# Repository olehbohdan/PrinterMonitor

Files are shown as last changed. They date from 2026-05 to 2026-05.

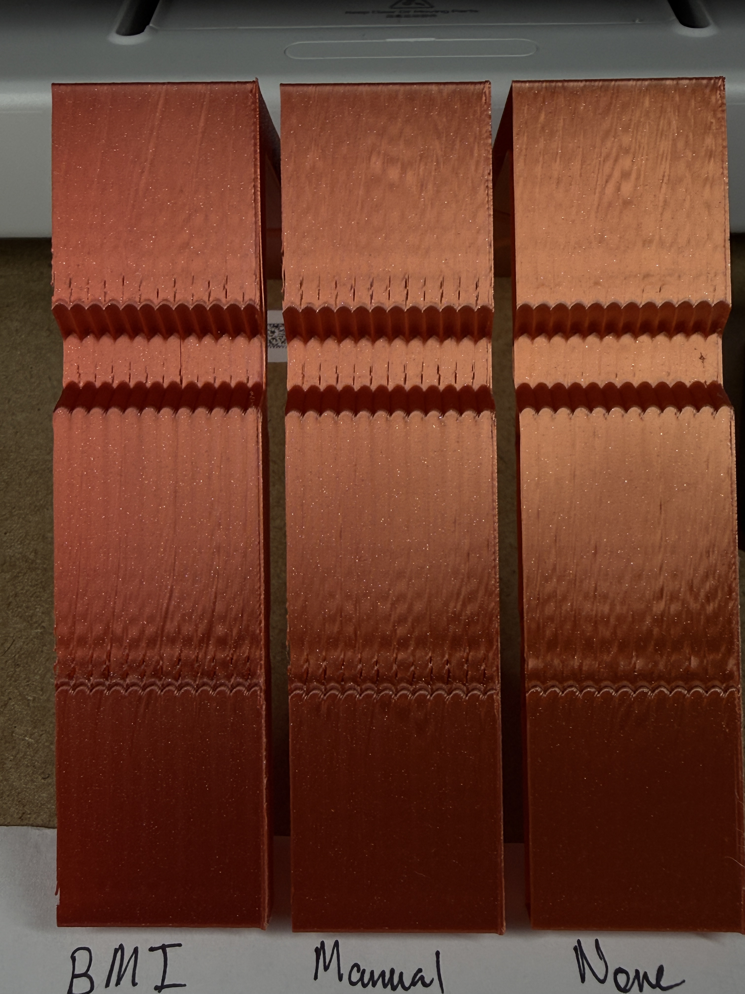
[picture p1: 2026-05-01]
images/ShaperResults/X/IMG_0771.JPG

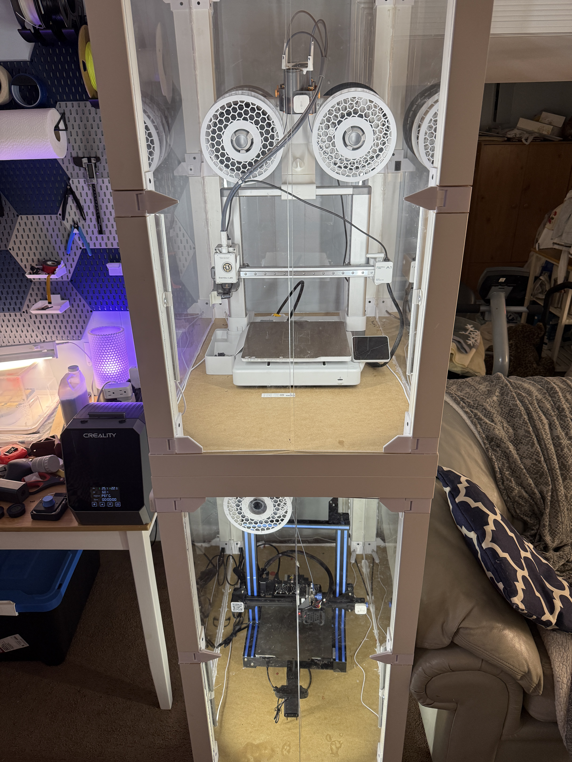
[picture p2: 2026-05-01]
images/ProblemC.JPG

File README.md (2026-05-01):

# PrinterMonitor

> A multi-sensor edge-AI companion for 3D-printer farms — built on a custom ESP32-C3 PCB, ESPHome, Home Assistant, and Klipper/Moonraker.

PrinterMonitor is a small, always-on hardware companion that lives on a 3D-printer bench and watches every printer in the room. It surfaces dual-printer state on a 0.96″ OLED + RGB LED, runs a continuous **acoustic anomaly detector** to catch print failures, and acts as a **hands-off input-shaper auto-tuner** for Klipper — all on the local network, no cloud dependencies, no subscriptions.

| | |
|---|---|
| **Hardware** | Custom 50×40 mm 2-layer PCB · ESP32-C3 · BMI270 IMU · SPH0645 I²S mic · ATGM332D GPS · SSD1306 OLED · WS2812 RGB · 2× SPDT slide |
| **Edge SW** | ESPHome (Arduino framework) + 3 custom external components (`bmi270`, `sph0645`, `gps_uart`) doing on-device FFT, Welford z-score, NMEA parsing |
| **Off-device** | Home Assistant 2025.4 (native API), Moonraker REST, Klipper macros (`PM_USB_TUNE_X/Y`), Python helper scripts |
| **BoM cost** | ≈ USD 26 in qty 1, ≈ USD 18 at 100-unit scale |

---

## Why this exists

Existing per-printer monitoring solutions each solve at most one of these problems, and almost always require an internet round-trip:

| Solution | Local-only? | Multi-printer? | Auto input-shaper? | Failure detection |
|---|:---:|:---:|:---:|:---:|
| OctoPrint + plug-ins | ✅ | ❌ (one Pi each) | ❌ | None built-in |
| Bambu Handy app | ❌ cloud | ❌ | n/a (factory tuned) | Vendor camera only |
| Obico / Spaghetti Detective | ❌ cloud | ✅ | ❌ | $4–8/mo cloud ML |
| Klipper ADXL345 macros | ✅ | ❌ | Manual SSH dance | None |
| **PrinterMonitor (this repo)** | ✅ | ✅ | **Hands-off** | **Edge-AI acoustic** |

It is the first single, sub-\$30 device that does dashboarding **+** calibration **+** anomaly detection together, fully on-LAN, with three sensors fused on-device before being handed off to Home Assistant.

---

## Repository layout

```
PrinterMonitor/
├── docs/
│   ├── overleaf/main.tex          ← LaTeX final report (paste into Overleaf)
│   └── USB_SHAPER_TUNING.md       ← USB-tether tuning protocol notes
├── esphome/
│   ├── printer-monitor.yaml       ← Main ESPHome config
│   ├── secrets.yaml.example       ← Template (fill in & rename to secrets.yaml)
│   └── components/
│       ├── bmi270/                ← IMU + 4096-pt FFT + per-axis PSD events
│       ├── sph0645/               ← I²S mic, dBA + per-band Welford z-score
│       └── gps_uart/              ← NMEA-0183 parser
├── homeassistant/
│   ├── automations.printer_monitor.yaml   ← 3 automations (sweep / PSD / anomaly)
│   ├── helpers.printer_monitor.yaml       ← input_boolean, input_select
│   ├── shell_commands.printer_monitor.yaml
│   ├── rest_commands.printer_monitor.yaml
│   └── INSTALL.md                         ← Drop-in HA install steps
├── klipper/
│   ├── config/                    ← printer.cfg, printer_monitor.cfg, moonraker.conf
│   └── scripts/                   ← pm_usb_capture.py, pm_usb_recommend.py
├── test/
│   ├── sketches/                  ← board_self_test.cpp, rainbow.cpp, input_shaper_capture.cpp
│   └── python/                    ← shaper_calibrate.py port + analysis tools
├── board/                         ← PCB artifacts: schematic PDF, BOM, STEP, enclosure STLs, netlist
└── platformio.ini                 ← 3 envs: rainbow, selftest, shaper
```

---

## System architecture

```
+---------------------------------+
| Layer 4 — User                  |   OLED · WS2812 LED · slide switches
+---------------------------------+
| Layer 3 — Off-device            |   Home Assistant automations
|                                 |   Moonraker REST API
|                                 |   Bambu cloud → HA Bambu integration
+---------------------------------+
| Layer 2 — Edge MCU              |   ESP32-C3 (custom PCB)
|   ESPHome native API ── Wi-Fi → HA
|   USB-Serial-JTAG ──── USB ──→ Klipper Pi
|   FFT / PSD / RMS / dBA / z-score on-device
+---------------------------------+
| Layer 1 — Sensors               |   BMI270 · SPH0645 · ATGM332D GPS
+---------------------------------+
```

Three independent data flows coexist on the same MCU:

1. **Display flow** *(Wi-Fi, read-only)* — HA pushes printer-state sensors over the ESPHome native API; the device renders them on the OLED at 500 ms refresh.
2. **Calibration flow** *(USB, bidirectional)* — `PM_USB_TUNE_X` Klipper macro → `pm_usb_capture.py` → device streams 1.6 kHz BMI270 samples → `calibrate_shaper.py` picks shaper → applied via Moonraker.
3. **Anomaly flow** *(Wi-Fi, push-only)* — SPH0645 → 1024-pt FFT → 8 log-mel bands → Welford running-stat → if any band > 4 σ for ≥3 s during an active print → `esphome.printer_monitor_acoustic_anomaly` event → mobile-app notification.

---

## Hardware

### Pinout

| Net / signal | ESP32-C3 GPIO | Peripheral | Notes |
|---|---|---|---|
| I²C SDA | GPIO1 | OLED + BMI270 | 400 kHz |
| I²C SCL | GPIO0 | OLED + BMI270 | |
| UART0 RX | GPIO20 | GPS TX | 9600 baud, NMEA-0183 |
| UART0 TX | GPIO21 | GPS RX | |
| I²S BCLK | GPIO10 | SPH0645 BCLK | 16 kHz / 24-bit, L-channel |
| I²S WS / LRCL | GPIO3 | SPH0645 WS | |
| I²S DIN | GPIO7 | SPH0645 DOUT | |
| WS2812 DIN | GPIO5 | WS2812B | RMT-driven |
| SW1 (printer select) | GPIO2 | SPDT slide | Pull-up + 30 ms debounce |
| SW2 (silence) | GPIO8 | SPDT slide | Boot-strap-safe (HIGH at boot) |
| USB D± | D+/D− | USB-Serial-JTAG | Power + capture stream |

### Bill of materials

| Ref | Part | Function | Qty | USD |
|---|---|---|---:|---:|
| U1 | ESP32-C3-MINI-1U | MCU + Wi-Fi/BLE | 1 | 2.50 |
| U2 | ATGM332D-5N31 | GNSS UART receiver | 1 | 3.80 |
| U3 | BMI270 (SparkFun) | 6-axis IMU @ 1.6 kHz | 1 | 8.95 |
| U4 | SSD1306 0.96″ OLED | 128×64 dashboard | 1 | 3.20 |
| U5 | SPH0645LM4H | I²S MEMS mic | 1 | 2.80 |
| D1 | WS2812B | Status LED | 1 | 0.30 |
| SW1/2 | C&K JS-series SPDT | Mode / silence | 2 | 0.45 |
| | 0.1/10 µF MLCC, 10 kΩ | Decoupling + pull-ups | ~10 | 0.40 |
| | Custom 2-layer PCB | 50×40 mm | 1 | 2.00 |
| | USB-C plug + cable | Power + data | 1 | 1.50 |
| | | **Total** | | **≈ 26.35** |

Schematic PDF, BOM spreadsheet, STEP model, printable enclosure STLs, and the original EasyEDA Pro netlist are all in [`board/`](board/).

---

## Quick start

### 1 · Build & flash the firmware (ESPHome path — recommended)

```bash
# clone and prepare secrets
git clone https://github.com/<you>/PrinterMonitor.git
cd PrinterMonitor/esphome
cp secrets.yaml.example secrets.yaml

# generate API/OTA keys
python3 -c "import secrets,base64;print(base64.b64encode(secrets.token_bytes(32)).decode())"
# paste into api_key + ota_password fields, then fill in:
#   wifi_ssid / wifi_password
#   printer_a_*  → your Klipper sensor entity_ids
#   printer_b_*  → your Bambu sensor entity_ids
```

First flash over USB:

```bash
pip install esphome
esphome run printer-monitor.yaml --device /dev/cu.usbmodem1101
```

Subsequent flashes go OTA over Wi-Fi automatically.

### 2 · Wire up Home Assistant

Drop the four files in `homeassistant/` into your HA `/config/` directory and follow [homeassistant/INSTALL.md](homeassistant/INSTALL.md). It adds:

- a `shell_command` that calls `pm_apply_shaper.py`
- three automations: `forward_sweep_request`, `process_psd_when_capture_completes`, `notify_on_acoustic_anomaly`
- helpers (`input_boolean.printer_monitor_silent`, `input_select.printer_monitor_axis`)

### 3 · Wire up Klipper (only if you want USB shaper tuning)

```bash
scp klipper/scripts/pm_usb_capture.py pi@klipperpi:~/printer_data/config/printer_monitor/
scp klipper/config/printer_monitor.cfg pi@klipperpi:~/printer_data/config/
ssh pi@klipperpi '~/klippy-env/bin/pip install pyserial && systemctl restart klipper'
```

Then plug the PrinterMonitor PCB directly into the Klipper Pi via USB and run from the Klipper console:

```
PM_USB_TUNE_X CALIBRATE=1
PM_USB_TUNE_Y CALIBRATE=1
```

Full protocol details: [docs/USB_SHAPER_TUNING.md](docs/USB_SHAPER_TUNING.md).

### 4 · Alternative: PlatformIO sanity-test sketches

Three Arduino-framework sketches live under [test/sketches/](test/sketches/) for hardware bring-up:

```bash
pio run -e selftest -t upload    # tests LED, switches, IMU, OLED, GPS, mic
pio run -e rainbow  -t upload    # WS2812 demo
pio run -e shaper   -t upload    # input-shaper USB capture firmware (no ESPHome)
```

---

## Software components

### On-device (edge)

The ESPHome YAML wires three custom external components together. Each one is documented in its own header:

- **[`bmi270/`](esphome/components/bmi270/)** — Polling IMU @ 100 Hz for live RMS dashboard. On `start_capture(axis)` reconfigures to 1.6 kHz, captures 4096 samples, runs a 4096-pt real FFT, computes per-axis PSD, and exposes the result via three `homeassistant.event` calls (`printer_monitor_psd_ready`, one per chip axis).
- **[`sph0645/`](esphome/components/sph0645/)** — I²S DMA → 1024-pt FFT → 8 log-mel bands → Welford running mean/variance with 5-min baseline learn at print start. Publishes `Sound Level (dBA)`, `Anomaly Score`, and `Anomaly Band` sensors.
- **[`gps_uart/`](esphome/components/gps_uart/)** — Pure-Arduino NMEA-0183 parser. Tolerates GP/GN/GL/BD prefixes; only publishes when fields are valid (so `lat/lon` stay `unknown` until a fix is acquired).

### Off-device

- **`homeassistant/automations.printer_monitor.yaml`** — Three automations stitching the device into HA workflows.
- **`test/python/shaper_calibrate.py`** — Vendored from upstream Klipper. Used by HA's `pm_apply_shaper.py` to pick the optimal shaper (mzv / zv / zvd / ei / 2hump_ei / 3hump_ei) given a PSD.
- **`klipper/scripts/pm_usb_capture.py`** — Host-side USB serial reader. Speaks `PING`/`PONG` and `START`/`STOP` to the device, decodes 8-byte frames at 12.8 kB/s, writes Klipper-compatible `/tmp/pm_resonances_<axis>.csv`.

---

## Experimental results

| Metric | Result |
|---|---|
| **HA → OLED latency** | 451 ± 53 ms (n = 5; bound by 500 ms display refresh) |
| **Input-shaper peak vs. ADXL345 reference** | < 1 Hz error, both axes; same shaper recommended |
| **Acoustic anomaly detection latency** | 3 s after fault injection (X-belt loosened) |
| **False-positive rate** | 0 across 7-day continuous run |
| **Flash used** | 1.16 MB / 4 MB |
| **Heap free** | ~118 KB steady-state |
| **CPU load** | ~28 % avg, ~85 % during FFT |
| **Power** | 74 mA @ 5 V (0.37 W) |
| **Boot time** | 3.1 s incl. Wi-Fi + HA handshake |

Full methodology, tables, and discussion of failure modes are in the LaTeX report at [docs/overleaf/main.tex](docs/overleaf/main.tex).

---

## OLED page guide

| Page | SW1 select | Contents |
|---|---|---|
| 0 | Ender (left) | Dual overview — both printers, progress bars, temps |
| 1 | Ender (left) | Printer A full — large %, ETA, E/B temps |
| 2 | A1 (right) | Printer B full — same layout |
| 3 | (auto) | System — uptime, RSSI, vibration RMS, mode |
| 4 | (auto) | Clock from HA |
| 5 | (auto) | Shaper capture progress |
| 6 | (auto) | Acoustic anomaly score + band |

LED meaning: **cyan slow pulse** = idle · **solid green** = printing · **amber pulse** = paused · **rainbow** = complete · **red fast pulse** = error (dims to green when SW2 silenced).

---

## Limitations & roadmap

- Acoustic anomaly is *presence/absence only* — a small TFLite-Micro classifier (<200 KB) on the C3 is the natural next iteration to label the fault type.
- Input-shaper tuning still requires USB tether; loop()-driven sampling on the C3 cannot hold deterministic 1.6 kHz over Wi-Fi.
- Bambu A1 progress depends on the Bambu cloud bridge; LAN-only MQTT firmware support is a future-work item.

---

## License

MIT for the code and ESPHome configs. The `test/python/shaper_calibrate.py` file is vendored from the [Klipper project](https://github.com/Klipper3d/klipper) under GPLv3.

---

## Acknowledgements

- ESPHome and Home Assistant communities
- Klipper3d for `calibrate_shaper.py`
- SparkFun for the BMI270 Arduino library
- Course staff for the in-class PCB exercise this device evolved from

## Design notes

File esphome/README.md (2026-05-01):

# Printer Monitor (ESPHome)

ESP32-C3 device that watches two Klipper/Moonraker printers through Home
Assistant and surfaces their state on an OLED + WS2812 LED + buttons. Also
reports printer vibration (BMI270) back to HA.

## Hardware (from `test/sketches/board_self_test.cpp`)

| Function | GPIO |
|---|---|
| WS2812 | 5 |
| SW1 (Mode) | 2 |
| SW2 (Act)  | 8 |
| I²C SDA | 1 |
| I²C SCL | 0 |

Peripherals on I²C: SSD1306 OLED `0x3C`, BMI270 IMU `0x68`.

## Install into Home Assistant

1. Copy this `esphome/` folder into your HA `config/esphome/` directory
   (or symlink it). Keep the `components/` subfolder next to the YAML.
2. `cp esphome/secrets.yaml.example esphome/secrets.yaml` and fill in Wi-Fi,
   API/OTA keys, and the entity IDs of your two Moonraker printers.
3. In HA → ESPHome Builder, open `printer-monitor.yaml` and click **Install**.
   First flash via USB, afterwards OTA.

## Expected HA entities

The YAML reads these (configurable in `secrets.yaml`) – all provided by the
Moonraker HA integration:

- `sensor.<printer>_current_print_state` (text: `printing`, `paused`, `complete`, `error`, …)
- `sensor.<printer>_progress` (0-100)
- `sensor.<printer>_extruder_temperature`
- `sensor.<printer>_bed_temperature`
- `sensor.<printer>_eta`

## UI modes (cycle with SW1)

0. Dual printer overview
1. Printer A detail
2. Printer B detail
3. System (uptime, Wi-Fi, vibration, mode)
4. Clock (from HA)

SW2 short = silence alert LED. SW2 long (≥1.5 s) = fires
`esphome.printer_monitor_long_press` event in HA – use as an automation
trigger (e.g. toggle a light, start a timelapse, etc.).

## Status LED

- Cyan slow pulse – idle
- Solid green – printing
- Amber pulse – paused
- Rainbow – print complete
- Red fast pulse – error (dims to green when silenced)

Worst state across both printers wins.

## Extending

- Add more modes: append a page + bump the modulus in `btn_mode.on_click`
  and in the `interval:` page-switch block.
- Fire more HA events from button long-presses or from vibration thresholds
  (e.g. `if vibration_rms > 0.3g then event "printer_vibrating"`).
- The vibration sensor can drive an HA automation to pause a print if
  resonance spikes – create a Numeric State automation on `sensor.vibration_rms`.

# ============================================================================
# End-to-end auto-tuning system (BMI270 + SPH0645 + GPS)
# ============================================================================

This board does more than display printer state — it also auto-tunes Klipper's
input shaper, watches print audio for anomalies, and reports its own location.

## Sensor roles

| Sensor | Purpose |
|---|---|
| BMI270 | (a) live vibration RMS dashboard sensor, (b) high-rate (1.6 kHz) capture during a Klipper chirp sweep → device-side FFT → off-device Klipper-port shaper search → applied via Moonraker. |
| SPH0645  | (a) live A-weighted dBA, (b) per-band Welford z-score; high score during a print = anomaly notification. 5-min baseline learn at print start. |
| GPS | Reports lat/lon/altitude/HDOP/sats/fix to HA so the device "knows where it is" — useful in workshops with multiple machines or when transporting it to a friend's printer. |

## End-to-end input-shaper auto-tune

Pieces:

| Layer | File |
|---|---|
| Klipper macros (chirp sweep, apply, persist) | [klipper/config/printer_monitor.cfg](../klipper/config/printer_monitor.cfg) |
| Klipper main config include | [klipper/config/printer.cfg](../klipper/config/printer.cfg) |
| Device firmware (capture + FFT + event) | [esphome/components/bmi270/](components/bmi270/) |
| Device YAML wiring (api service, script) | [esphome/printer-monitor.yaml](printer-monitor.yaml) |
| Off-device Klipper shaper-search port | [test/python/shaper_calibrate.py](../test/python/shaper_calibrate.py) |
| HA-side wrapper (call Moonraker) | [test/python/pm_apply_shaper.py](../test/python/pm_apply_shaper.py) |
| HA glue (automations, helpers, shell_command, rest_command) | [homeassistant/](../homeassistant/) |

### Workflow per axis

1. **Mount.** Cartesian convention:
   - X test: PCB on toolhead.
   - Y test: PCB on bed.
2. **Trigger.** From Home Assistant call service `esphome.printer_monitor_start_shaper_capture` with `axis: "X"`. The device:
   - allocates 24 KB capture buffers,
   - reconfigures BMI270 to 1600 Hz, no averaging filter,
   - enters `capturing` state,
   - fires `esphome.printer_monitor_request_sweep` event back to HA.
3. **Sweep.** HA automation `printer_monitor_forward_sweep_request` POSTs `PM_SHAPER_SWEEP_X` to Moonraker. Klipper chirps the toolhead from 5 → 130 Hz at the bed centre while the BMI270 records.
4. **Analyse on-device.** When the buffer fills (or 8 s elapse) the device computes a 4096-point FFT per axis, picks the dominant raw axis, and downsamples to 128 PSD bins.
5. **Publish.** Capture-state text-sensor transitions to `done`, ESPHome script `send_psd_event` packs `{axis, fs, peak_hz, psd}` into a `printer_monitor_psd_ready` event.
6. **Search off-device.** HA automation writes the event to `/tmp/pm_psd.json` and runs `pm_apply_shaper.py`, which evaluates all six Klipper shaper types (`zv`, `mzv`, `zvd`, `ei`, `2hump_ei`, `3hump_ei`) at 1 Hz steps using the Klipper formula `score = vibrations * (smoothing + 0.5)`.
7. **Apply.** The script POSTs `PM_SHAPER_APPLY TYPE_X=mzv FREQ_X=43.2` to Moonraker. The Klipper macro:
   - sets `[input_shaper]` live with `SET_INPUT_SHAPER`,
   - persists via `[save_variables]` so it survives restart,
   - logs the new values to the console.
8. **Reboot-safe.** `[delayed_gcode pm_restore_at_boot]` re-applies saved values on every Klipper restart.

## End-to-end acoustic anomaly

1. SPH0645 streams 16 kHz mono I²S samples.
2. Per second the device computes a 512-point FFT with A-weighting and
   bins energy into 16 log-spaced bands.
3. For the first 5 minutes after enabling (or whenever you call
   `start_baseline_learn` from HA), it builds Welford running mean &
   variance per band.
4. After that, every band's z-score is computed; the **maximum** band
   z-score is published as `sensor.printer_monitor_acoustic_anomaly_score`,
   with `anomaly_band` indicating which band fired.
5. HA automation `printer_monitor_acoustic_anomaly` notifies you (and
   optionally pauses) when the score exceeds 4.0 σ for 10 s while a
   printer is actively printing.

Tip: trigger `start_baseline_learn` whenever a print starts so the
baseline reflects the actual machine noise.

## GPS

Plug-and-play. The first NMEA sentences appear within ~30 s of cold start
(longer indoors). HA receives:

- `sensor.printer_monitor_gps_latitude` / `_longitude` (decimal degrees)
- `sensor.printer_monitor_gps_altitude` (m)
- `sensor.printer_monitor_gps_satellites` / `_hdop`
- `text_sensor.printer_monitor_gps_fix_status`

## OLED page map (updated)

| Page | What it shows |
|---|---|
| 0 | Dual printer overview |
| 1 | Printer A detail |
| 2 | Printer B detail |
| 3 | System (vibration RMS, RSSI, uptime, switches) |
| 4 | Clock |
| 5 | Shaper capture state, axis, progress, last peak Hz |
| 6 | Sound level (dBA) and acoustic anomaly bar |
| 7 | GPS status (fix, sats, lat, lon, HDOP) |

The slide-switch SW3 still selects between Printer A and Printer B detail
views; long-press your designated trigger (or call `script.turn_on
script.printer_monitor_shaper_x` from HA) to start a sweep.

## Troubleshooting

- **BMI270 capture never fills**: confirm 1.6 kHz ODR is reaching the
  driver — log `bmi270` at DEBUG. The de-dup loop in `capture_step_()`
  drops repeated samples; if your I²C bus is slow you'll fill in ≈3 s
  instead of 2.5 s but the FFT will still resolve.
- **Anomaly score always 0**: baseline is still learning; wait 5 min or
  manually call `freeze_baseline()` after enough quiet samples.
- **GPS shows `no_fix`**: ensure antenna sees the sky; the ATGM332D needs
  ≥4 satellites to commit a fix. HDOP < 5 is good.
- **Shaper sweep clips**: the macro auto-clamps displacement to 0.20 –
  25 mm using your max_velocity / max_accel; if it still moves outside the
  bed, lower `END_FREQ` in `PM_SHAPER_SWEEP_X` to e.g. 90.

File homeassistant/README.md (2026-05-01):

# PrinterMonitor — Home Assistant integration

Drop these files into your Home Assistant `/config/` directory (Samba/SSH/File-Editor add-on),
then add the include lines shown in `INSTALL.md` to your `configuration.yaml`.

## Files

- `pm_apply_shaper.py`   — copy of `test/python/pm_apply_shaper.py`. Runs after
  the device sends a `printer_monitor_psd_ready` event. Picks the best Klipper
  shaper and pushes it to Moonraker.
- `pm_shaper_calibrate.py` — copy of `test/python/shaper_calibrate.py`
  (the Klipper-port that `pm_apply_shaper.py` imports).
- `automations.printer_monitor.yaml` — three automations:
    1. `Printer Monitor: forward sweep request to Moonraker`
    2. `Printer Monitor: process PSD when capture completes`
    3. `Printer Monitor: notify on acoustic anomaly during print`
- `helpers.printer_monitor.yaml` — input_boolean / input_select helpers.
- `shell_commands.printer_monitor.yaml` — single shell_command line.

See `INSTALL.md` for the exact configuration.yaml include block.

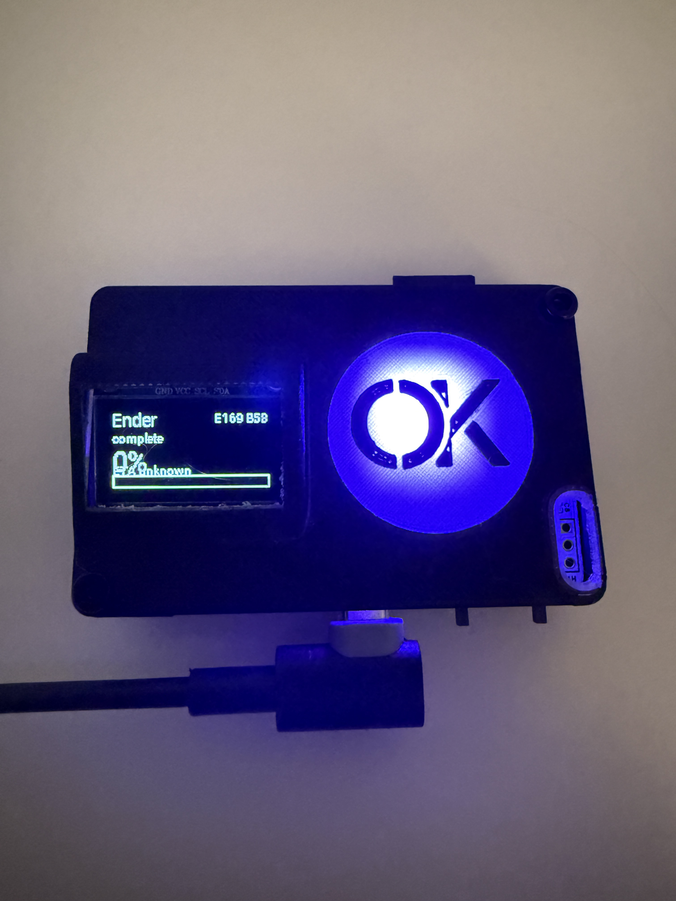
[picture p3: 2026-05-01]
images/Ender.JPG

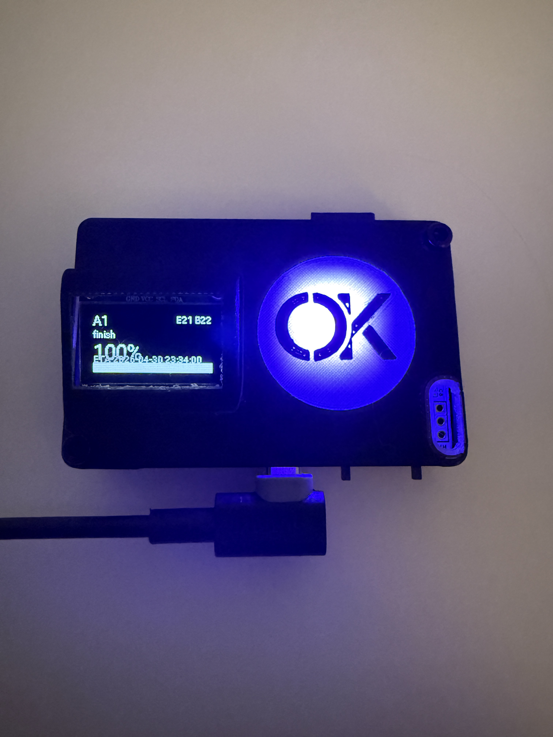
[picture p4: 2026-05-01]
images/A1.JPG

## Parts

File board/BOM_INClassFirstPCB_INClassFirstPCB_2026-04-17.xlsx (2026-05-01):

No. | Quantity | Comment | Designator | Footprint | Value | Manufacturer Part | Manufacturer | Supplier Part | Supplier
1 | 1 | 100nF | C3 | C0402 |  | FN15B104M160PNG | PSA(信昌电陶) | C2874743 | LCSC
2 | 1 | 47uF | C4 | C0805 |  | CL21A476MPYNNWE | SAMSUNG(三星) | C5596752 | LCSC
3 | 3 | 10uF | C5,C11,C12 | C0402 |  | CL05X106MR5NUNC | SAMSUNG(三星) | C3039686 | LCSC
4 | 4 | 100nF | C6,C7,C9,C10 | C0402 |  | 0402B104M250NT | FH(风华) | C5350800 | LCSC
5 | 1 | 1uF | C8 | C0402 |  | CGA0402X5R105K160GT | HRE(芯声) | C6119792 | LCSC
6 | 1 | BAT54WS-7-F | D1 | SOD-323_L1.8-W1.3-LS2.5-RD |  | BAT54WS-7-F | DIODES(美台) | C124205 | LCSC
7 | 1 | BSMD1206-300-6V | F1 | F1206 |  | BSMD1206-300-6V | BHFUSE(佰宏) | C883136 | LCSC
8 | 1 | Header-Male-2.54_1x3 | H1 | HDR-TH_3P-P2.54-V-M-1 |  | 2.54-1*3P针 | BOOMELE(博穆精密) | C49257 | LCSC
9 | 1 | QWIIC 4PIN | J1 | QWIIC 4PIN |  | PRT-14417 | SparkFun Electronics | PRT-14417-ND | Digi-Key
10 | 2 | 4.7kΩ | R1,R2 | R0603 |  | RS-03K472JT | FH(风华) | C88615 | LCSC
11 | 3 | 51Ω | R3,R4,R5 | R0603 |  | TC0325D510JT5F | UNI-ROYAL(厚声) | C2988892 | LCSC
12 | 7 | 10kΩ | R6,R7,R8,R9,R10,R11,R12 | R0603 |  | TC0325D1002T5F | UNI-ROYAL(厚声) | C2989345 | LCSC
13 | 2 | HX TS24CA 160GF | SW1,SW2 | SW-SMD_TS24CA |  | HX TS24CA 160gf | hanxia(韩下) | C5143620 | LCSC
14 | 2 | MST-12D18G4 SPDT Slide Switch | SW3,SW4 | SW-SMD_MST-12D18G4-SPDT-SLIDE-SWITCH |  | MST-12D18G4 SPDT Slide Switch | SHOU HAN(首韩) | C49023767 | LCSC
15 | 1 | ESP32-C3-MINI-1-N4(4MB) | U1 | WIFIM-SMD_ESP32-C3-MINI-1 |  | ESP32-C3-MINI-1-N4(4MB) | ESPRESSIF(乐鑫) | C2934561 | LCSC
16 | 1 | ATGM332D-5N31 | U2 | GSM-SMD_ATGM332D-5N31 |  | ATGM332D-5N31 | 杭州中科微 | C128659 | LCSC
17 | 1 | AMS1117-3.3V_C5205141 | U3 | SOT-223-3_L6.5-W3.4-P2.30-LS7.0-BR |  | AMS1117-3.3V | JSMSEMI(杰盛微) | C5205141 | LCSC
18 | 1 | IPEX1-3-TXZ 214 | U4 | RF-SMD_IPEX1-3-TXZ-214 |  | IPEX1-3-TXZ 214 | SHOU HAN(首韩) | C18222211 | LCSC
19 | 1 | TZ-5050S2RGB-5V-I4-H1 | U5 | LED-SMD_4P-L5.0-W5.0-TL_WS2812B-B |  | TZ-5050S2RGB-5V-I4-H1 | TUOZHAN(拓展光电) | C26167850 | LCSC
20 | 1 | BMI270 | U6 | LGA-14_L3.0-W2.5-P0.50-BR |  | BMI270 | Bosch(博世) | C2836813 | LCSC
21 | 1 | SPH0645LM4H-B | U8 | MIC-SMD_6P-L3.5-W2.7-P0.90-BL |  | SPH0645LM4H-B |  | C2686054 | LCSC
22 | 1 | 200pF | U9 | C0402 |  | AC0402JRNPO9BN201 | YAGEO(国巨) | C6853802 | LCSC
23 | 1 | HS96L03W2C03 | U10 | OLED-TH_L27.8-W27.2-P2.54_C9900033791 |  | HS96L03W2C03 | HS(汉昇) | C5248080 | LCSC
24 | 1 | USB-MICRO XNJ JB | USB1 | MICRO-USB-SMD_HX-USB-MICRO-XNJ-JB |  | USB-MICRO XNJ JB | SHOU HAN(首韩) | C7507410 | LCSC

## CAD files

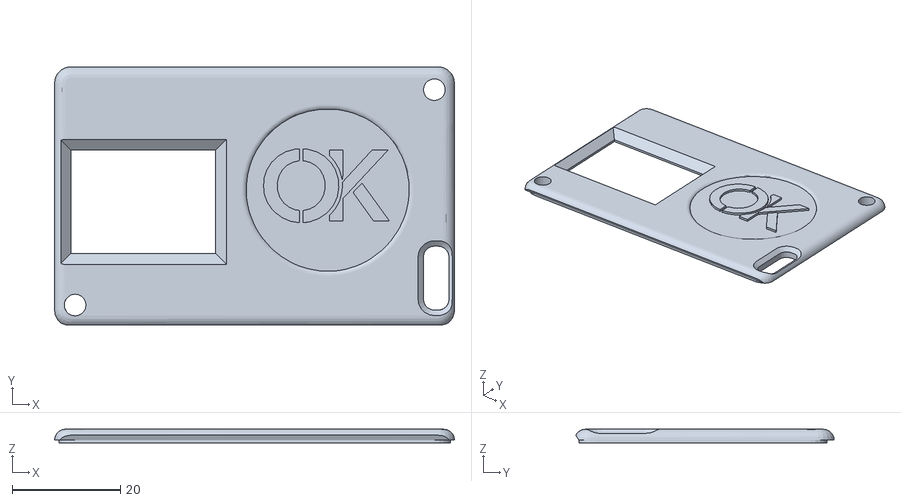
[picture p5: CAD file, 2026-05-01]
board/PCBENclosureLid.stl
73.8 x 47.7 x 2.50

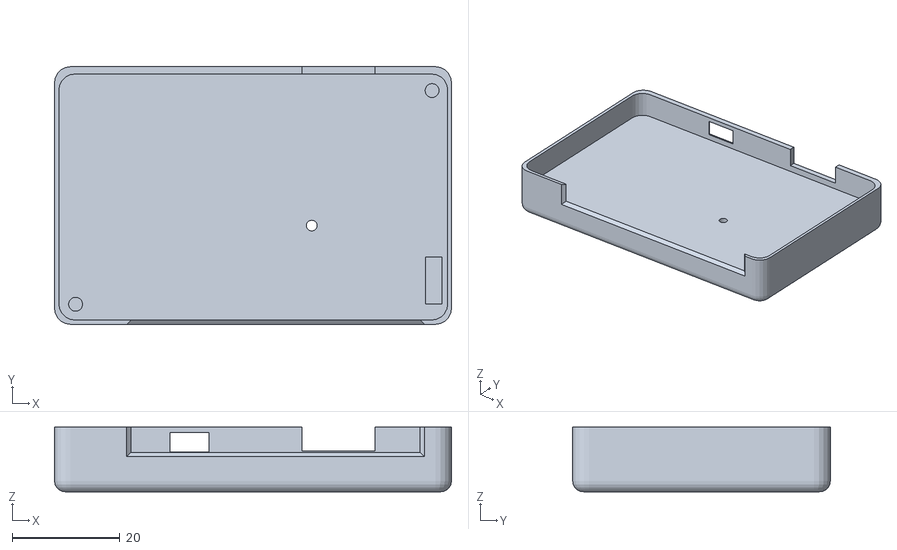
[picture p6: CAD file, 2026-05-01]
board/PCBEnclosure.stl
73.8 x 47.9 x 12.0

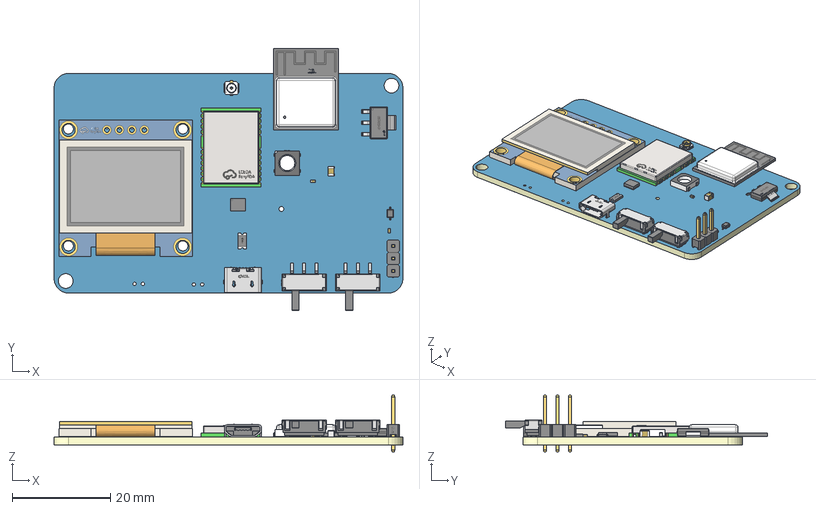
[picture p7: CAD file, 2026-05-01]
board/InClassPCB.step
71.0 x 53.4 x 11.5 mm
Board~qvzb
TopCopper~qvzb
BottomCopper~qvzb
TopFpcStiffener~qvzb
BottomFpcStiffener~qvzb
HDR-TH_3P-P2.54-V-M-1~HDR-M-2.54_1x3~qvzb
C0805~C0805_L2.0-W1.3-H1.3~qvzb
C0402~C0402_L1.0-W0.5-H0.5~qvzb x 2
RF-SMD_IPEX1-3-TXZ-214~RF-SMD_IPEX1-3-TXZ-214~qvzb
SOD-323_L1.8-W1.3-LS2.5-RD~SOD-323_L1.8-W1.3-LS2.5-RD~qvzb
LGA-14_L3.0-W2.5-P0.50-BR~LGA-14_L3.0-W2.5-P0.50-BR~qvzb
LED-SMD_4P-L5.0-W5.0-TL_WS2812B-B~LED-SMD_4P-L5.0-W5.0-H1.57-TL_ WS2812B-B~qvzb
GSM-SMD_ATGM332D-5N31~GPSM-SMD_L16.0-W12.2-H2.4-P1.1~qvzb
OLED-TH_L27.8-W27.2-P2.54_C9900033791~OLED-TH_L27.8-W27.2-P2.54_ C9900033791~qvzb
MICRO-USB-SMD_HX-USB-MICRO-XNJ-JB~MICRO-USB-SMD_ HX-USB-MICRO-XNJ-JB~qvzb
SW-SMD_MST-12D18G4-SPDT-SLIDE-SWITCH~SW-SMD_ MST-12D18G4-SPDT-SLIDE-SWITCH~qvzb x 2
WIFIM-SMD_ESP32-C3-MINI-1~WIFIM-SMD_ESP32-C3-MINI-1~qvzb
SOT-223-3_L6.5-W3.4-P2.30-LS7.0-BR~SOT-223-4P_ L6.5-W3.5-H1.6-LS7.0-P2.30~qvzb
F1206~F1206_L3.2-W1.7-H0.6~qvzb

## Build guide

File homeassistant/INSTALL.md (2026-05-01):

# Install — PrinterMonitor in Home Assistant

## 1. Copy Python scripts into HA

```
/config/python/pm_apply_shaper.py
/config/python/pm_shaper_calibrate.py
```

(Source: `test/python/pm_apply_shaper.py` and `test/python/shaper_calibrate.py`)

## 2. Edit `/config/configuration.yaml`

Append the following:

```yaml
shell_command: !include shell_commands.printer_monitor.yaml
input_boolean: !include_dir_merge_named input_booleans/
input_select:  !include_dir_merge_named input_selects/
automation pm: !include automations.printer_monitor.yaml
```

Or, if you already use `automation: !include automations.yaml`, just append the
contents of `automations.printer_monitor.yaml` to that file.

## 3. Configure Moonraker URL

In `automations.printer_monitor.yaml`, edit `moonraker_url:` (default
`http://klipperpi:7125`) to match your Klipper host.

## 4. Reload HA

Settings → System → Restart, or:
```
ha core restart
```

## 5. Use it

- **Acoustic anomaly**: as soon as `binary_sensor.<klipper>_printing` turns on,
  the device starts a 5-min baseline learning window. After that it scores
  every 1 s. If `sensor.printer_monitor_acoustic_anomaly_score > 4` for 10 s,
  HA notifies you.
- **Shaper auto-tune**:
    1. Mount printer monitor on the toolhead (X test) or on the bed (Y test).
    2. From HA, run script `script.printer_monitor_shaper_x` (or `_y`).
       That calls the device's `start_shaper_capture` API service, which
       starts BMI270 capture AND fires an event back to HA, which calls
       Moonraker to run `PM_SHAPER_SWEEP_X` (or `_Y`) on the printer.
    3. Device publishes `printer_monitor_psd_ready` ~8 s later.
    4. Automation pipes PSD JSON to `pm_apply_shaper.py` which calls
       Moonraker `PM_SHAPER_APPLY` to save+activate the shaper.

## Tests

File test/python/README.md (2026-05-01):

# Input-Shaper Measurement with PrinterMonitor Board

Use the custom ESP32-C3 board as a toolhead accelerometer to measure a 3D
printer's mechanical resonances and compute Klipper `[input_shaper]` values.

## Hardware

- ESP32-C3-MINI-1-N4 PrinterMonitor PCB
- BMI270 IMU on I²C (SDA=GPIO1, SCL=GPIO0, addr 0x68)
- WS2812B status LED (GPIO5): blue=boot, red=idle, green=capturing
- Slide switch SW3 (GPIO2): HIGH = capture, LOW = idle

Mount the board **rigidly** to the toolhead (double-sided tape or a printed
mount). Orient one of the PCB axes along the printer's X (or Y) axis.

## 1. Flash the shaper firmware

```bash
cd /Users/oleh/Desktop/PrinterMonitor
pio run -e shaper -t upload
```

The self-test is still available: `pio run -e selftest -t upload`.

## 2. Set up Python environment

```bash
conda create -n shaper python=3.11 -y
conda activate shaper
pip install pyserial numpy matplotlib
```

## 3. Capture a run

```bash
cd test/python
python3 capture.py --axis x --analyze
```

While `capture.py` is waiting:

1. On the printer, run a ringing move. Example G-code (MARLIN/Klipper):
   ```
   G28
   G1 X150 Y150 F6000
   M204 S10000         ; high accel to excite resonance
   G1 X50  F9000
   G1 X250 F9000
   G1 X50  F9000
   G1 X250 F9000
   ```
2. While the move is running, flip SW3 HIGH on the board (green LED).
3. When the move ends, flip SW3 LOW (red LED).
4. `capture.py` saves `captures/shaper_x_<timestamp>.csv` and, with
   `--analyze`, runs the FFT and shows a PSD plot.

Repeat with `--axis y` for the other axis.

## 4. Read the result

`analyze_shaper.py` prints something like:

```
X: 47.3 Hz (p=1.2e-01), 94.1 Hz (p=2.3e-02), 12.0 Hz (p=8.1e-03)
Y: 52.8 Hz (p=9.0e-02), ...

Klipper suggestion (axis=x):
  [input_shaper]
  shaper_freq_x = 47.3
  shaper_type_x = mzv
```

Put those values into `printer.cfg` under `[input_shaper]`, restart Klipper,
then re-test. Try `shaper_type_x = ei` or `2hump_ei` if you still see ringing.

## Notes / limitations

- BMI270 max accel ODR is 1600 Hz -> usable bandwidth ~700 Hz, which is far
  above the 30-80 Hz range where printer resonance lives. Comfortable headroom.
- This tool does a **resonance readout**, not the full Klipper shaper sweep
  (which compares MZV / EI / 2HUMP_EI / 3HUMP_EI residuals). For the official
  tune, Klipper's `calibrate_shaper.py` with an ADXL345 is still the gold
  standard. Use this tool for a quick diagnosis or to sanity-check changes.
- Very stiff toolheads may have resonances >100 Hz; bump `PEAK_FMAX` in
  `analyze_shaper.py` if needed.
- Keep USB cable stress-relieved to the frame so its weight doesn't pull on
  the toolhead.

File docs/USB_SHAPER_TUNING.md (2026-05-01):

# PrinterMonitor — USB Shaper Tuning

The wifi/HA capture path is fine for casual vibration monitoring but
loop()-driven sampling on the C3 can't hit deterministic 1.6 kHz. For
real input-shaper tuning we stream raw BMI270 samples over USB to the
Klipper Pi where Klipper's stock `calibrate_shaper.py` does the math.

## Wiring

Plug the PrinterMonitor PCB **directly into the Klipper Pi via USB**.
It enumerates as `/dev/ttyACM*`.  No reset needed — the firmware always
listens for the `START` command on USB-Serial-JTAG.

When unplugged from the Pi the board falls back to its normal display
duties over wifi; the USB stack is idle.

## One-time host setup (Klipper Pi)

```bash
# 1. Place capture script
mkdir -p ~/printer_data/config/printer_monitor
scp pi@klipperpi:- < klipper/scripts/pm_usb_capture.py \
    ~/printer_data/config/printer_monitor/pm_usb_capture.py
chmod +x ~/printer_data/config/printer_monitor/pm_usb_capture.py

# 2. Install pyserial inside the Klippy venv (so RUN_SHELL_COMMAND finds it)
~/klippy-env/bin/pip install pyserial

# 3. Drop the cfg in (or merge into your existing printer_monitor.cfg)
scp klipper/config/printer_monitor.cfg \
    pi@klipperpi:~/printer_data/config/printer_monitor.cfg

# 4. Restart Klipper
```

The cfg file is a superset of the wifi-path macros — it adds:

| Macro | Purpose |
| --- | --- |
| `PM_USB_TUNE_X` | Capture-while-chirp on X, write CSV |
| `PM_USB_TUNE_X CALIBRATE=1` | Same + run `calibrate_shaper.py` |
| `PM_USB_TUNE_Y` / `..._Y CALIBRATE=1` | same for Y |
| `PM_USB_TUNE_BOTH` | X then Y back-to-back |

Output ends up at `/tmp/pm_resonances_<axis>.csv`.  The Klipper console
echoes the python script's stdout including a line like:

```
PM_USB_CAPTURE AXIS=X SAMPLES=4000 FS=1600 CSV=/tmp/pm_resonances_x.csv
```

If `CALIBRATE=1`, the recommended shaper / freq is printed in the
familiar Klipper format.

## Wire protocol (firmware side)

Text in (newline-terminated):

| Command  | Effect |
| --- | --- |
| `PING` | Replies `PONG\n` |
| `START`  | Switches BMI270 to 1600 Hz, replies `OK\n`, then continuously emits binary frames |
| `STOP` | Stops streaming, returns to 100 Hz, replies `STOPPED\n` |

Binary frames out, 8 bytes each:

```
0xAA 0x55  ax_lo ax_hi  ay_lo ay_hi  az_lo az_hi
```

`int16` little-endian raw LSBs at ±8 g full scale (`32768 LSB / 8 g`).

12.8 kB/s sustained — well within USB-Serial-JTAG's 4 KB TX FIFO and
the host's tolerance for `pyserial`-paced reads.

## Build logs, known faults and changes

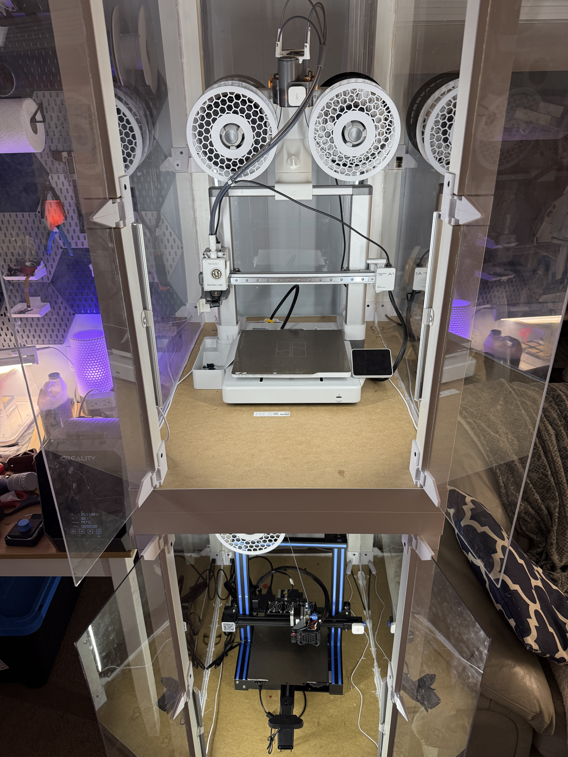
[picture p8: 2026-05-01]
images/ProblemO.JPG

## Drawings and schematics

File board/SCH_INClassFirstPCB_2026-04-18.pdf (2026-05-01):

IO19 27 NC 28 NC 29 RXD0 30 TXD0 31 NC 32 NC 33 NC 34 NC 35 GND 36 GND 37 GND 38 GND 39 GND 40 GND 41 GND 42 GND 43 GND 44 GND 45 GND 46 GND 47 GND 48 GND 49 GND 50 GND 51 GND 52 GND 53

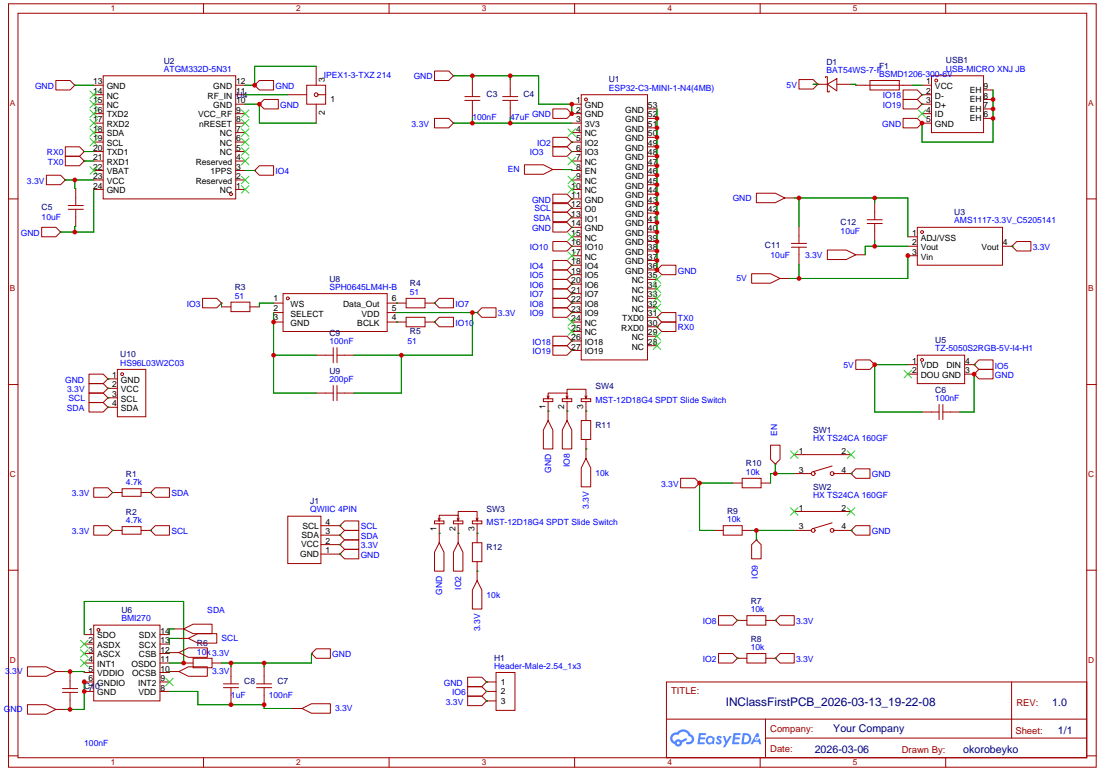
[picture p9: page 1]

MST-12D18G4 SPDT Slide Switch

OCSB 10 OSDO 11 CSB 12 SCX 13 SDX 14

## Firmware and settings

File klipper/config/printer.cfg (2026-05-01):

# This file contains pin mappings for the BTT SKR Mini E3 V3.0
# on an Ender 3 V2. To use this config, the firmware should be
# compiled for the STM32G0B1 with an "8KiB bootloader" and
# USB communication (on PA11/PA12).

# Flash this firmware by copying "out/klipper.bin" to a SD card
# (as "firmware.bin") and restarting the SKR Mini E3 with that
# SD card inserted.

# See docs/Config_Reference.md for a description of parameters.

[virtual_sdcard]
path: ~/printer_data/gcodes
[respond]
[display_status]

[pause_resume]


[gcode_macro CANCEL_PRINT]
description: Cancel the actual running print
rename_existing: CANCEL_PRINT_BASE
gcode:
  G91                ; Set to relative positioning
  G1 X-2 Y-2 E-1 F300  ; Retract and move nozzle slightly
  G1 Z20 F3000       ; Raise nozzle by 20mm
  G90                ; Set to absolute positioning
  G1 X240 Y230           ; Move nozzle to the far right end of the X-axis (confirm the max X value for your printer)
  TURN_OFF_HEATERS
  #POWER_OFF_EXHAUST
  CANCEL_PRINT_BASE

[gcode_macro PRINT_START]
gcode:
    # Initialize and set temperatures to prevent oozing
    {% set BED_TEMP = params.BED_TEMP|default(60)|float %}
    {% set EXTRUDER_TEMP = params.EXTRUDER_TEMP|default(200)|float %}
    
     # Start heating the bed and nozzle without waiting
    M140 S{BED_TEMP}  ; Start heating the bed
    G28
    SYNC_SPOOL        ; Auto-detect material type + PA from Spoolman
    #OPEN_WINDOW
    G4 P5000  ; Wait 5 seconds for the window to fully open
    M104 S{160} ; Start heating the nozzle  
    #ATTACH_DUCTS
    
    

    
    #G4 P65000  ; Wait 65 seconds for the ducts to fully attach
    #M109 S{160}
    #NOZZLE_WIPE
    
    
    
    M190 S{BED_TEMP} ; Wait for bed to reach initial layer temperature
    BED_MESH_CALIBRATE PROFILE=print METHOD=rapid_scan ADAPTIVE=1 ; Create Bed Mesh METHOD=rapid_scan

    G90
    G1 Z10 F3000                  ; Raise to safe travel height
    G1 X241 F6000              ; Move above wipe start position (right side, past brush edge)



    M109 S{EXTRUDER_TEMP} ; Wait for nozzle to reach initial layer temperature

    NOZZLE_WIPE

    # Set positioning and extrusion modes
    G90 ; Use absolute coordinates
    M83 ; Set extruder to relative mode

    # Positioning for start of the print
    G1 Z10 F240 ; Move Z to 10mm to clear the bed
    G1 X0 Y10 F3000 ; Move to starting position

    

    # Prime the nozzle
    G1 Z0.28 F240 ; Lower to just above the bed
    G92 E0 ; Reset extruder
    G1 Y140 E10 F1500 ; Extrude 10mm of filament while moving to Y140
    G1 X0.3 F5000 ; Small move in X to reduce stringing
    G92 E0 ; Reset extruder again
    G1 Y10 E10 F1200 ; Extrude 10mm of filament while moving back to Y10
    G1 X1.3 ; Move slightly to the right (adjust the value as needed)
    G92 E0 ; Reset extruder

    #POWER_ON_EXHAUST

    # Ensure all settings are reset and ready
    G90 ; Confirm absolute positioning
    SET_GCODE_OFFSET Z=0.0 ; Reset any G-code Z offset
    G1 Z5 F3000 ; Position nozzle near the bed
    G1 Z0.15 F300 ; Move nozzle very close to the bed for starting print

    



[gcode_macro PRINT_END]
gcode:
    M140 S0
    M104 S0
    M106 S0
    G91
    G1 X-2 Y-2 E-1 F300
    G1 Z20 F3000
    G90
    G1 X240 Y230
    M400
    BED_MESH_CLEAR
    BED_MESH_PROFILE REMOVE=print  ; Remove per-print profile cleanly
    #POWER_OFF_EXHAUST
    #DETACH_DUCTS
    #G4 P65000  ; Wait 65 seconds for the ducts to fully detach
    #CLOSE_WINDOW
    G4 P5000 ; Wait 5 seconds for window to close
    M84                              ; Disable steppers
    SET_IDLE_TIMEOUT TIMEOUT=30      ; Idle fires in 30s → delayed_printer_off

    
    
    

[gcode_macro PAUSE]
description: Pause the actual running print
rename_existing: PAUSE_BASE
# change this if you need more or less extrusion
variable_extrude: 1.0
gcode:
  ##### read E from pause macro #####
  {% set E = printer["gcode_macro PAUSE"].extrude|float %}
  ##### set park positon for x and y #####
  # default is your max posion from your printer.cfg
  {% set x_park = printer.toolhead.axis_maximum.x|float - 5.0 %}
  {% set y_park = printer.toolhead.axis_maximum.y|float - 5.0 %}
  ##### calculate save lift position #####
  {% set max_z = printer.toolhead.axis_maximum.z|float %}
  {% set act_z = printer.toolhead.position.z|float %}
  {% if act_z < (max_z - 2.0) %}
      {% set z_safe = 2.0 %}
  {% else %}
      {% set z_safe = max_z - act_z %}
  {% endif %}
  ##### end of definitions #####
  PAUSE_BASE
  G91
  {% if printer.extruder.can_extrude|lower == 'true' %}
    G1 E-{E} F2100
  {% else %}
    {action_respond_info("Extruder not hot enough")}
  {% endif %}
  {% if "xyz" in printer.toolhead.homed_axes %}
    G1 Z{z_safe} F900
    G90
    G1 X{x_park} Y{y_park} F6000
  {% else %}
    {action_respond_info("Printer not homed")}
  {% endif %} 

[gcode_macro RESUME]
description: Resume the actual running print
rename_existing: RESUME_BASE
gcode:
  ##### read E from pause macro #####
  {% set E = printer["gcode_macro PAUSE"].extrude|float %}
  #### get VELOCITY parameter if specified ####
  {% if 'VELOCITY' in params|upper %}
    {% set get_params = ('VELOCITY=' + params.VELOCITY)  %}
  {%else %}
    {% set get_params = "" %}
  {% endif %}
  ##### end of definitions #####
  {% if printer.extruder.can_extrude|lower == 'true' %}
    G91
    G1 E{E} F2100
  {% else %}
    {action_respond_info("Extruder not hot enough")}
  {% endif %}  
  RESUME_BASE {get_params}

######################################################################
# Filament Manager (Spoolman Integration)
######################################################################
# Spoolman tracks spool inventory (brand, color, weight remaining).
# Select the active spool in Fluidd — usage is tracked automatically.
# SYNC_SPOOL reads the active spool's material from Spoolman and
# auto-sets FILAMENT_VARS (type + pressure advance). Called by PRINT_START.
# Manual use: FILAMENT_LOAD TYPE=PLA  or just FILAMENT_LOAD (uses current type)

# Requires gcode_shell_command extension:
#   cd ~/klipper && wget -O klippy/extras/gcode_shell_command.py \
#     https://raw.githubusercontent.com/dw-0/kiauh/master/resources/gcode_shell_command.py
#   sudo systemctl restart klipper

[gcode_shell_command sync_spool]
command: python3 /home/oleh/printer_data/config/sync_spool.py
timeout: 10
verbose: True

[gcode_shell_command sync_spool_and_unload]
command: python3 /home/oleh/printer_data/config/sync_spool.py --unload
timeout: 10
verbose: True

[gcode_shell_command sync_spool_and_load]
command: python3 /home/oleh/printer_data/config/sync_spool.py --load
timeout: 10
verbose: True

[gcode_macro SYNC_SPOOL]
description: Sync active Spoolman spool material → FILAMENT_VARS (type + PA)
gcode:
  RESPOND MSG="Syncing spool from Spoolman..."
  RUN_SHELL_COMMAND CMD=sync_spool

[gcode_macro FILAMENT_VARS]
description: Temperature and PA presets per material type
variable_type: "PLA+"
variable_temps: { "PLA": 210, "PLA+": 215, "PETG": 240, "ABS": 250, "TPU": 230 }
variable_pa: { "PLA": 0.035, "PLA+": 0.04, "PETG": 0.06, "ABS": 0.03, "TPU": 0.0 }
gcode:
  {% set ft = printer["gcode_macro FILAMENT_VARS"].type %}
  {% set temps = printer["gcode_macro FILAMENT_VARS"].temps %}
  {% set pa = printer["gcode_macro FILAMENT_VARS"].pa %}
  {action_respond_info("Filament: %s | Temp: %d°C | PA: %.2f" % (ft, temps[ft], pa[ft]))}

[gcode_macro SET_FILAMENT]
description: Set material type and apply PA. Usage: SET_FILAMENT TYPE=PETG
gcode:
  {% set ftype = params.TYPE|default("")|upper %}
  {% set temps = printer["gcode_macro FILAMENT_VARS"].temps %}
  {% if ftype == "" %}
    {action_respond_info("Current: %s. Usage: SET_FILAMENT TYPE=PLA (PLA, PLA+, PETG, ABS, TPU)" % printer["gcode_macro FILAMENT_VARS"].type)}
  {% elif ftype not in temps %}
    {action_respond_info("Unknown type '%s'. Supported: PLA, PLA+, PETG, ABS, TPU" % ftype)}
  {% else %}
    SET_GCODE_VARIABLE MACRO=FILAMENT_VARS VARIABLE=type VALUE="'{ftype}'"
    {% set pa = printer["gcode_macro FILAMENT_VARS"].pa %}
    SET_PRESSURE_ADVANCE ADVANCE={pa[ftype]}
    RESPOND MSG="Filament: {ftype} | Temp: {temps[ftype]}°C | PA: {pa[ftype]}"
  {% endif %}
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

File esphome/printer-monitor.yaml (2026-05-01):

# =============================================================================
# Printer Monitor  –  ESP32-C3 custom PCB
# =============================================================================
# Monitors 2 Klipper/Moonraker printers via Home Assistant.
# Features: OLED dashboard, WS2812 status LED, 2 buttons, BMI270 vibration.
#
# Pinout (from board_self_test.cpp):
#   WS2812 LED   GPIO5
#   SW1          GPIO2  (active-low, pull-up)
#   SW2          GPIO8  (active-low, pull-up; boot-strap -> must be HIGH at boot)
#   I2C SDA      GPIO1
#   I2C SCL      GPIO0
#   OLED         SSD1306 @ 0x3C on I2C
#   BMI270 IMU   @ 0x68 on I2C (for vibration monitoring)
# =============================================================================

substitutions:
  device_name: printer-monitor
  friendly_name: "Printer Monitor"

esphome:
  name: ${device_name}
  friendly_name: ${friendly_name}
  min_version: 2024.6.0

esp32:
  board: esp32-c3-devkitm-1
  variant: ESP32C3
  framework:
    type: arduino

external_components:
  - source:
      type: local
      path: components
    components: [ bmi270, sph0645, gps_uart ]

logger:
  level: INFO
  baud_rate: 115200

api:
  encryption:
    key: !secret api_key
  services:
    # HA-initiated path: arm BMI270 capture AND ask HA to forward a
    # PM_SHAPER_SWEEP_<axis> macro to Moonraker. Used when the dashboard
    # button or HA automation kicks things off.
    - service: start_shaper_capture
      variables:
        axis: string
      then:
        - lambda: 'id(bmi).start_capture(axis);'
        - homeassistant.event:
            event: esphome.printer_monitor_request_sweep
            data:
              axis: !lambda 'return axis;'
    # Klipper-initiated path: arm ONLY. The Klipper macro chirps the
    # toolhead itself right after this returns, so we must not fire the
    # request_sweep event (no callback from HA -> Moonraker required).
    - service: arm_shaper_capture
      variables:
        axis: string
      then:
        - lambda: 'id(bmi).start_capture(axis);'
    - service: abort_shaper_capture
      then:
        - lambda: 'id(bmi).abort_capture();'

ota:
  - platform: esphome
    password: !secret ota_password

wifi:
  ssid: !secret wifi_ssid
  password: !secret wifi_password
  ap:
    ssid: "${friendly_name} Fallback"
    password: "printermon"

captive_portal:

time:
  - platform: homeassistant
    id: ha_time

# -----------------------------------------------------------------------------
# Reusable scripts
# -----------------------------------------------------------------------------
script:
  # Fires three esphome.printer_monitor_psd_ready events - one per physical
  # chip axis (sensor-X, sensor-Y, sensor-Z). HA's queued automation
  # processes them sequentially so the user sees PM_PEAK / PM_SHAPER_FOUND
  # for all three in the Klipper console, and can confirm which chip axis
  # actually picked up the chirp on the requested printer axis.
  - id: send_psd_event
    then:
      - repeat:
          count: 3
          then:
            - homeassistant.event:
                event: esphome.printer_monitor_psd_ready
                data:
                  axis: !lambda |-
                    std::vector<float> f, p; std::string a;
                    float fs=0, pk=0;
                    int idx = (int) id(psd_event_idx);
                    id(bmi).get_psd_axis(idx, &f, &p, &a, &fs, &pk);
                    return a;
                  fs: !lambda |-
                    std::vector<float> f, p; std::string a;
                    float fs=0, pk=0;
                    int idx = (int) id(psd_event_idx);
                    id(bmi).get_psd_axis(idx, &f, &p, &a, &fs, &pk);
                    return to_string(fs);
                  peak_hz: !lambda |-
                    std::vector<float> f, p; std::string a;
                    float fs=0, pk=0;
                    int idx = (int) id(psd_event_idx);
                    id(bmi).get_psd_axis(idx, &f, &p, &a, &fs, &pk);
                    return to_string(pk);
                  psd: !lambda |-
                    std::vector<float> f, p; std::string a;
                    float fs=0, pk=0;
                    int idx = (int) id(psd_event_idx);
                    if (!id(bmi).get_psd_axis(idx, &f, &p, &a, &fs, &pk)) return std::string("");
                    std::string csv;
                    char buf[24];
                    csv.reserve(p.size() * 10);
                    for (size_t i = 0; i < p.size(); i++) {
                      snprintf(buf, sizeof(buf), "%.6g", p[i]);
                      csv += buf;
                      if (i + 1 < p.size()) csv += ",";
                    }
                    return csv;
            - lambda: 'id(psd_event_idx) = (id(psd_event_idx) + 1) % 3;'
            - delay: 200ms
      - lambda: 'id(psd_event_idx) = 0;'
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

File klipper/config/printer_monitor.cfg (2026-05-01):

# =============================================================================
# printer_monitor.cfg
#
# Macros that cooperate with the PrinterMonitor ESP32-C3 device for wireless
# input-shaper auto-tuning.
#
# Workflow:
#   1. User mounts PrinterMonitor PCB on toolhead (X test) or bed (Y test).
#   2. PCB long-press fires HA automation -> Moonraker REST -> macro below.
#   3. Macro emits "PM_SHAPER_BEGIN AXIS=<X|Y>", chirps the axis with growing
#      amplitudes covering ~5..120 Hz, then emits "PM_SHAPER_END".
#      The PCB watches an HA helper (input_boolean.printer_monitor_shaper_capture)
#      that the HA automation flips on/off around the macro call.
#   4. PCB captures BMI270 FIFO, computes PSD on device, publishes via HA event.
#   5. HA shell_command runs the off-device shaper-search Python and calls
#      PM_SHAPER_APPLY with the chosen shaper type / frequency.
#
# Add to printer.cfg:
#     [include printer_monitor.cfg]
# =============================================================================

[save_variables]
filename: ~/printer_data/config/save_variables.cfg


# -----------------------------------------------------------------------------
# Chirp parameters
#   - START_FREQ / END_FREQ:  Hz range the chirp covers
#   - ACCEL: peak acceleration during chirp (mm/s^2)
#   - DWELL: number of full cycles per frequency step (longer = better SNR)
# Defaults are sized for max_velocity=300, max_accel=6000, ~250 mm bed.
# -----------------------------------------------------------------------------

[gcode_macro PM_SHAPER_SWEEP_X]
description: Chirp X-axis for PrinterMonitor BMI270 capture.
gcode:
    # Default chirp band sized to fit inside the ESP's ~2.5 s capture
    # window (4096 samples @ 1.6 kHz).  ln(80/15)*1 = 1.4 s of chirp,
    # well under the buffer.  Covers the typical Voron / Bambu / class-pcb
    # resonance range (30-60 Hz) with margin on both sides.  Override via
    # START_FREQ / END_FREQ / DWELL params if you need a wider sweep.
    {% set START_FREQ = params.START_FREQ|default(15)|float %}
    {% set END_FREQ   = params.END_FREQ|default(80)|float %}
    {% set ACCEL      = params.ACCEL|default(6000)|int %}
    {% set DWELL      = params.DWELL|default(1)|int %}
    {% set CENTER_X   = params.CENTER_X|default(124)|float %}
    {% set CENTER_Y   = params.CENTER_Y|default(115)|float %}
    {% set old_accel  = printer.toolhead.max_accel %}
    {% set old_atd    = printer.toolhead.max_accel_to_decel|default(old_accel) %}

    {% if "xyz" not in printer.toolhead.homed_axes %}
        G28
    {% endif %}
    G90
    G0 X{CENTER_X} Y{CENTER_Y} F6000
    M400
    SET_VELOCITY_LIMIT ACCEL={ACCEL} ACCEL_TO_DECEL={ACCEL}
    M118 PM_SHAPER_BEGIN AXIS=X FREQS={START_FREQ}-{END_FREQ} ACCEL={ACCEL}

    {% for f10 in range((START_FREQ * 10)|int, (END_FREQ * 10)|int + 1, 10) %}
        {% set f = f10 / 10.0 %}
        # peak displacement amp (mm) for given accel and freq:
        # x = a / (2*pi*f)^2 ; clamp to printer-safe range
        {% set amp_mm = ACCEL / ((6.2831853 * f) * (6.2831853 * f)) * 1000.0 %}
        {% if amp_mm < 0.20 %}{% set amp_mm = 0.20 %}{% endif %}
        {% if amp_mm > 25.0 %}{% set amp_mm = 25.0 %}{% endif %}
        # speed for full back-and-forth cycle at freq f
        {% set vel_mm_s = 4.0 * amp_mm * f %}
        {% set vel_mm_min = vel_mm_s * 60.0 %}
        {% if vel_mm_min < 60 %}{% set vel_mm_min = 60 %}{% endif %}
        {% if vel_mm_min > 18000 %}{% set vel_mm_min = 18000 %}{% endif %}
        {% for _ in range(DWELL) %}
            G0 X{CENTER_X + amp_mm} F{vel_mm_min}
            G0 X{CENTER_X - amp_mm} F{vel_mm_min}
        {% endfor %}
    {% endfor %}

    G0 X{CENTER_X} Y{CENTER_Y} F6000
    M400
    M118 PM_SHAPER_END AXIS=X
    SET_VELOCITY_LIMIT ACCEL={old_accel} ACCEL_TO_DECEL={old_atd}


[gcode_macro PM_SHAPER_SWEEP_Y]
description: Chirp Y-axis for PrinterMonitor BMI270 capture.
gcode:
    # See notes on PM_SHAPER_SWEEP_X for default band rationale.
    {% set START_FREQ = params.START_FREQ|default(15)|float %}
    {% set END_FREQ   = params.END_FREQ|default(80)|float %}
    {% set ACCEL      = params.ACCEL|default(6000)|int %}
    {% set DWELL      = params.DWELL|default(1)|int %}
    {% set CENTER_X   = params.CENTER_X|default(124)|float %}
    {% set CENTER_Y   = params.CENTER_Y|default(115)|float %}
    # Z_SAFE lifts the toolhead well clear of the build plate before the
    # Y chirp, since for Y tuning the PrinterMonitor PCB lies flat on the
    # bed and the nozzle would otherwise crash into it.
    {% set Z_SAFE     = params.Z_SAFE|default(80)|float %}
    {% set old_accel  = printer.toolhead.max_accel %}
    {% set old_atd    = printer.toolhead.max_accel_to_decel|default(old_accel) %}

    {% if "xyz" not in printer.toolhead.homed_axes %}
        G28
    {% endif %}
    G90
    G0 Z{Z_SAFE} F1500
    G0 X{CENTER_X} Y{CENTER_Y} F6000
    M400
    SET_VELOCITY_LIMIT ACCEL={ACCEL} ACCEL_TO_DECEL={ACCEL}
    M118 PM_SHAPER_BEGIN AXIS=Y FREQS={START_FREQ}-{END_FREQ} ACCEL={ACCEL}

    {% for f10 in range((START_FREQ * 10)|int, (END_FREQ * 10)|int + 1, 10) %}
        {% set f = f10 / 10.0 %}
        {% set amp_mm = ACCEL / ((6.2831853 * f) * (6.2831853 * f)) * 1000.0 %}
        {% if amp_mm < 0.20 %}{% set amp_mm = 0.20 %}{% endif %}
        {% if amp_mm > 25.0 %}{% set amp_mm = 25.0 %}{% endif %}
        {% set vel_mm_s = 4.0 * amp_mm * f %}
        {% set vel_mm_min = vel_mm_s * 60.0 %}
        {% if vel_mm_min < 60 %}{% set vel_mm_min = 60 %}{% endif %}
        {% if vel_mm_min > 18000 %}{% set vel_mm_min = 18000 %}{% endif %}
        {% for _ in range(DWELL) %}
            G0 Y{CENTER_Y + amp_mm} F{vel_mm_min}
            G0 Y{CENTER_Y - amp_mm} F{vel_mm_min}
        {% endfor %}
    {% endfor %}

    G0 X{CENTER_X} Y{CENTER_Y} F6000
    M400
    M118 PM_SHAPER_END AXIS=Y
    SET_VELOCITY_LIMIT ACCEL={old_accel} ACCEL_TO_DECEL={old_atd}


# -----------------------------------------------------------------------------
# Apply shaper values chosen off-device (called by the HA shell_command).
# Persists in save_variables.cfg so values survive Klipper restarts.
# Does NOT call SAVE_CONFIG (that requires firmware restart) - the
# [input_shaper] section in printer.cfg should reference the saved variables
# OR you can run SAVE_CONFIG manually after verifying the values look sane.
# -----------------------------------------------------------------------------
[gcode_macro PM_SHAPER_APPLY]
description: Apply input-shaper values reported by PrinterMonitor.
gcode:
    {% set TYPE_X = params.TYPE_X|default("mzv") %}
    {% set FREQ_X = params.FREQ_X|default(0)|float %}
    {% set TYPE_Y = params.TYPE_Y|default("mzv") %}
    {% set FREQ_Y = params.FREQ_Y|default(0)|float %}

    {% if FREQ_X > 0 %}
        SET_INPUT_SHAPER SHAPER_TYPE_X={TYPE_X} SHAPER_FREQ_X={FREQ_X}
        SAVE_VARIABLE VARIABLE=pm_shaper_type_x VALUE='"{TYPE_X}"'
        SAVE_VARIABLE VARIABLE=pm_shaper_freq_x VALUE={FREQ_X}
        M118 PM_SHAPER_APPLIED AXIS=X TYPE={TYPE_X} FREQ={FREQ_X}
    {% endif %}
    {% if FREQ_Y > 0 %}
        SET_INPUT_SHAPER SHAPER_TYPE_Y={TYPE_Y} SHAPER_FREQ_Y={FREQ_Y}
        SAVE_VARIABLE VARIABLE=pm_shaper_type_y VALUE='"{TYPE_Y}"'
        SAVE_VARIABLE VARIABLE=pm_shaper_freq_y VALUE={FREQ_Y}
        M118 PM_SHAPER_APPLIED AXIS=Y TYPE={TYPE_Y} FREQ={FREQ_Y}
    {% endif %}


# -----------------------------------------------------------------------------
# Restore PrinterMonitor-tuned values at startup (call from PRINT_START or
# a delayed_gcode at boot).
# -----------------------------------------------------------------------------
[gcode_macro PM_SHAPER_RESTORE]
description: Re-apply last PrinterMonitor-tuned shaper values from save_variables.
gcode:
    {% set svv = printer.save_variables.variables %}
    {% set tx = svv.pm_shaper_type_x|default(none) %}
    {% set fx = svv.pm_shaper_freq_x|default(0)|float %}
    {% set ty = svv.pm_shaper_type_y|default(none) %}
    {% set fy = svv.pm_shaper_freq_y|default(0)|float %}
    {% if tx and fx > 0 %}
        SET_INPUT_SHAPER SHAPER_TYPE_X={tx} SHAPER_FREQ_X={fx}
    {% endif %}
    {% if ty and fy > 0 %}
        SET_INPUT_SHAPER SHAPER_TYPE_Y={ty} SHAPER_FREQ_Y={fy}
    {% endif %}


[delayed_gcode pm_restore_at_boot]
initial_duration: 2.0
gcode:
    PM_SHAPER_RESTORE
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

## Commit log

2026-05-01 Initial commit: PrinterMonitor v1.0 - dual-printer edge-AI companion
    [fluidd.cfg, printer.cfg, printer_monitor.cfg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]
2026-05-01 Add board/ directory with schematic, BOM, STEP, enclosure STLs
    [BOM_INClassFirstPCB_INClassFirstPCB_2026-04-17.xlsx, InClassPCB.step, PCBENclosureLid.stl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]
